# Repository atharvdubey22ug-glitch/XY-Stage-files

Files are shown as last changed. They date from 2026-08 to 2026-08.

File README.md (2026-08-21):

License: The hardware design files in this repository are provided under the F2R Hardware License v1.0. Personal, educational, experimental, and non-commercial research use is permitted with attribution. Commercial manufacture, sale, or commercial use requires prior written permission from F2R.

# XY-Stage-files
Below are the step file and bill of materials for XY stage one (Use PETG for printing)

 F2R Flexure Stage © 2026 Atharv Dubey is licensed under CC BY-NC-SA 4.0.

 To view a copy of this license, visit:
 https://creativecommons.org/licenses/by-nc-sa/4.0/

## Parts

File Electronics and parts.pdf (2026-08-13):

Electronics

3 BYJ stepper motors
https://robocraze.com/products/5v-stepper-motor?variant=40193680507033&country=IN&currency=INR (https://robocraze.com/products/5v-stepper-motor?variant=40193680507033&country=IN&currency=INR)

Convert the motors from Uni Polar to Bi polar by following this tutorial with this the motors become more precise

https://www.youtube.com/watch?v=pOMRzBdshEY&t=94s

3 TMC 2208 stepper drivers https://robu.in/product/tmc2208-stepper-motor-driver-module/

3 Stepper driver expansion boards obu.in/product/red-a4988-stepper-motor-driver-controller-board/?gad_source=1&gad_campa ignid=20381096599&gbraid=0AAAAADvLFWeWZweoIdbgVLavXCJuIP1wi (http://obu.in/product/red-a4988-stepper-motor-driver-controller-board/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)

12V 2A DC power supply
https://www.amazon.in/Electronic-Spices-Supply-Adapter-Connector/dp/B0CWTQWN3F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 (https://www.amazon.in/Electronic-Spices-Supply-Adapter-Connector/dp/B0CWTQWN3F)

Arduino Nano
https://robocraze.com/products/nano-development-board-compatible-with-arduino?_pos=1&_sid=7fe53113e&_ss=r (https://robocraze.com/products/nano-development-board-compatible-with-arduino?_pos=1&_sid=7fe53113e&_ss=r)

WS28182 Ring Light :
https://www.flyrobo.in/7-bit-ws2812-5050-rgb-led-built-full-color-driver-colored-light-round?tracking=ads (https://www.flyrobo.in/7-bit-ws2812-5050-rgb-led-built-full-color-driver-colored-light-round?tracking=ads) (the one I used is no longer available , you can use any light source btw)

Jumper wires and a barrel jack connector for power

3D Printed Parts and screws

(Print with PETG only)

Main Body: | ThreadScope 3D parts (https://drive.google.com/drive/folders/1FtQhOv9wb6JjXkL4TnOp5wyPSOwtop3y?usp=sharing)
Motor couplers x3: | ThreadScope 3D parts (https://drive.google.com/drive/folders/1FtQhOv9wb6JjXkL4TnOp5wyPSOwtop3y?usp=sharing)

### 3 M3 hex screws and nuts (Onlyscrews.com got good sets)

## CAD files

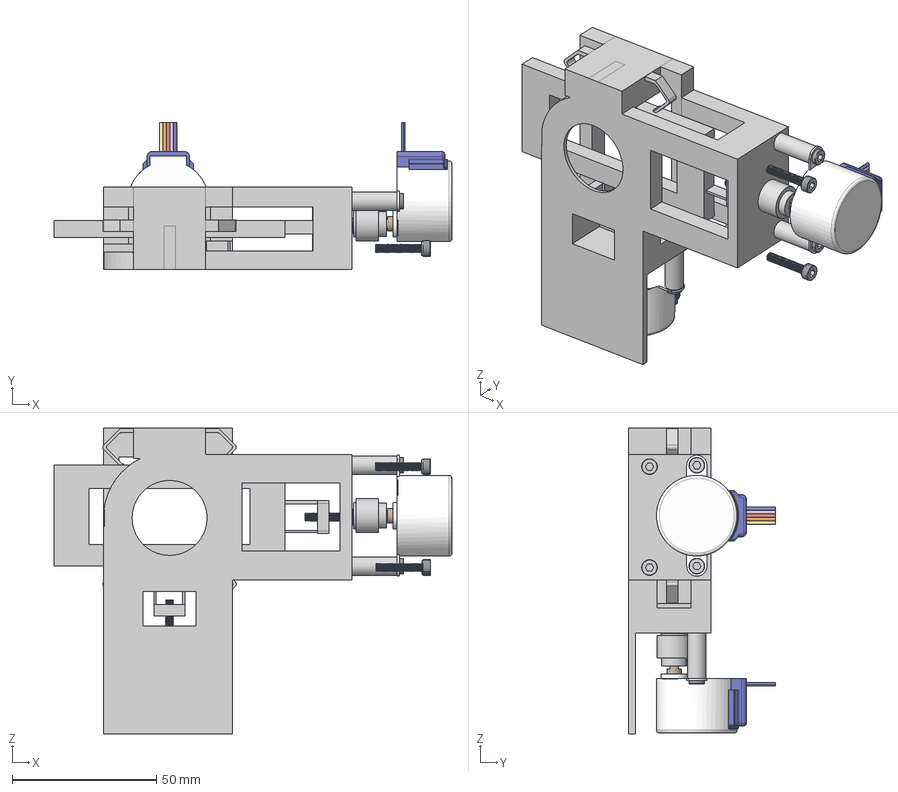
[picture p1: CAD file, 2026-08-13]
XY STAGE UPDATED.step
138.1 x 50.9 x 106.2 mm
Metal Rod (2)
Wires (2)
Metal Rod (1)
Wires (1)

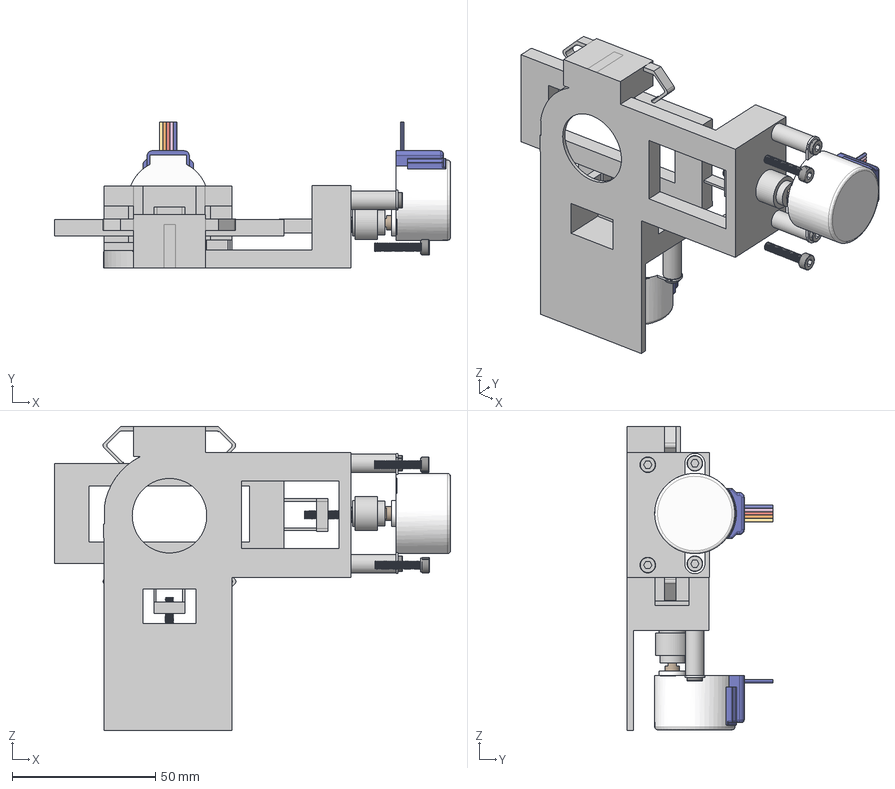
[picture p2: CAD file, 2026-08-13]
XY STAGE 1.step
138.1 x 50.9 x 106.2 mm
Metal Rod (2)
Wires (2)
Metal Rod (1)
Wires (1)

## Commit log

2026-11-04 Add illustrated XY Lab assembly guide
    Exploded-view and cutaway renders from the full assembly CAD showing
    the captured M3 nuts, the two-piece screw coupler and motor mounting.
    README now links the guide and lists the XY Lab hardware.
2026-11-04 Use corrected coupler cap in assembly guide
    The cap is a plain sleeve: 5.5 mm counterbore for the M3 head and a
    4 mm through-hole in the closed end. All renders and the step 2 text
    updated to match.
2026-11-04 Replace XY Lab.step with full assembly and corrected coupler cap
    New file is the full XY Lab assembly (body, couplers, motors, hardware).
    Both coupler caps now use the corrected design: plain sleeve with a
    5.5 mm head pocket and 4 mm through-hole in a 1.5 mm closed end.
    README lists which parts to print.
2026-11-04 Show lead screw between coupler cap and cup in exploded views
    Explosion order now follows assembly order: cap, screw, cup, motor.
2026-11-08 Add XY Lab assembly animation
    Looping GIF at the top of the README and assembly guide, plus the
    1080p MP4. Exploded still moves to the guide's parts section.
2026-11-08 Keep exploded-view image under the assembly GIF in README
2026-11-08 Add M3 washer between wall and coupler cap; grease advice
    DIN 125 M3 washer on each lead screw, between the fixed wall and the
    coupler cap, for smooth rotation. Added to the parts lists, step 2/3
    text, all renders, the GIF and the MP4. Grease tip added to README
    and assembly guide, plus troubleshooting rows.
2026-11-09 Fix Y-axis washer sitting inside the wall in renders
    Y washer now sits on the actual wall face (35.58 mm). The Y drive
    train is shifted 2.59 mm outward so it clears the wall the same way
    the X axis does. GIF, MP4, exploded, Y-axis and assembled views
    re-rendered.
2026-11-12 Add wiring diagrams for Arduino Nano and ESP32 versions
    Add circuit diagrams for both XY Lab controller options and extend
    README Step 3 with the ESP32 pin map alongside the Nano one.
2026-11-12 Add stage firmware and web controller
    - firmware/xy_lab_nano: STEP/DIR jog firmware for the Arduino Nano,
    matching the README pin map
    - firmware/xy_lab_esp32: current ESP32 jog firmware
    - firmware/web_controller_esp32 + software/stage_controller.py:
    browser controller with live camera view and repeatability tests
    - README: firmware links, serial commands and web controller setup
2026-11-12 Add web controller, its ESP32 firmware and README setup
    - software/stage_controller.py: browser controller with live camera
    view, repeatability test suite and CSV logging
    - firmware/web_controller_esp32: matching ESP32 firmware (v7) with
    precision moves, move acknowledgements and hard halt
    - README: links to all firmware, serial commands, web controller setup
    and the Y EN pin note
2026-11-12 Add web controller (Python) and README setup instructions
    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
2026-11-12 README: link firmware and web controller, add setup steps
    Step 6 now links the Nano and ESP32 jog firmware, lists the serial
    commands, and explains how to set up the web controller, including the
    Y EN pin note. Repository files table gains firmware/ and software/.
